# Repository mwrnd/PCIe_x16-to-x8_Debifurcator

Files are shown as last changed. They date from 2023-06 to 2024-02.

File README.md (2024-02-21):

# PCIe x16-to-x8 Debifurcator

Designed for use with the [Alveo U25](https://www.xilinx.com/products/boards-and-kits/alveo/u25.html) which has an x16 PCIe interface that is bifurcated to two x8 interfaces, one for the [SFC9250 X2 GbE Controller](https://www.xilinx.com/products/boards-and-kits/x2-series.html) and the other for the [XCZU19EG FPGA](https://www.xilinx.com/products/silicon-devices/soc/zynq-ultrascale-mpsoc.html#eg). This board connects the FPGA's PCIe x8 interface directly to a host system. The X2 GbE Controller is disconnected and ignored.

Only a straddle-mount PCIe x16 Connector is required, such as: [10025026-10103TLF](https://www.trustedparts.com/en/search/10025026-10103TLF), [10025026-10003TLF](https://www.trustedparts.com/en/search/10025026-10003TLF), or [10146027-A40010LF](https://www.trustedparts.com/en/search/10146027-A40010LF).

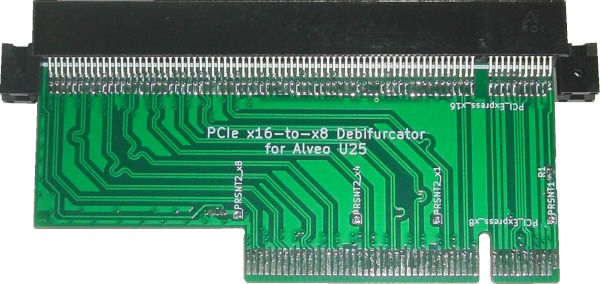
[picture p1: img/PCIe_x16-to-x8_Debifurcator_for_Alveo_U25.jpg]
PCIe x16-to-x8 Debifurcator for Alveo U25


Related Projects: [alveo_u25_notes](https://github.com/mwrnd/alveo_u25_notes), [AlveoU25_JTAG_Adapter](https://github.com/mwrnd/AlveoU25_JTAG_Adapter), [ATX_Boot_Delay](https://github.com/mwrnd/ATX_Boot_Delay)

# Testing and Use Example

I have been able to [successfully test an XDMA design](https://github.com/mwrnd/alveo_u25_notes) using the debifurcator and an Alveo U25 in a system that does not support PCIe Bifurcation.

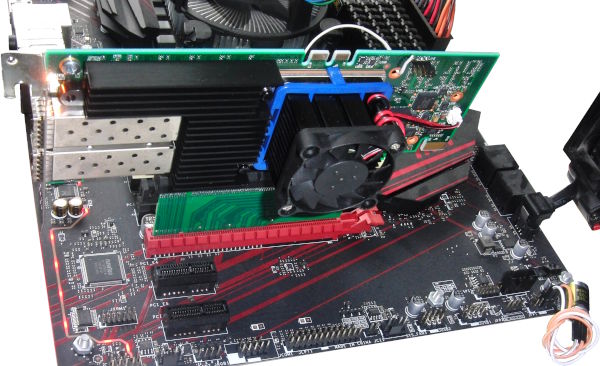
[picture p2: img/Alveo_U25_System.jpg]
PCIe x16-to-x8 Debifurcator with Alveo U25 In-System


The XCZU19EG uses its ARM processor to configure the FPGA's Programmable Logic (PL) bitstream. It is difficult to get this to finish within the [PCIe Specification's 100ms time limit](https://pcisig.com/specifications/ecr_ecn_process?speclib=100+ms). Motherboard boot must be delayed to allow the FPGA to configure itself before PCIe devices are enumerated by the host system. This can be accomplished by toggling the POWER button, then pressing and holding the RESET button for a second before releasing it. Or, [connect a capacitor across the reset pins of an ATX motherboard's Front Panel Header](https://github.com/mwrnd/ATX_Boot_Delay):

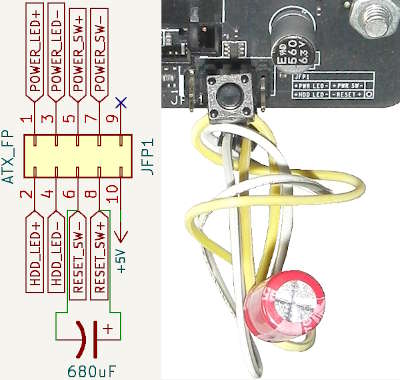
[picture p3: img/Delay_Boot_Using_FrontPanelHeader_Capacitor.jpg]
Motherboard Boot Delay Capacitor


# PCB Layout

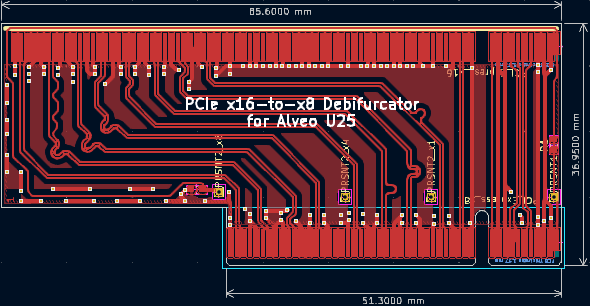
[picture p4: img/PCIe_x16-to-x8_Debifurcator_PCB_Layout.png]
PCIe x16-to-x8 Debifurcator PCB Layout


All differential pairs are length-matched to within 1mm both inter-pair and intra-pair.

# Schematic

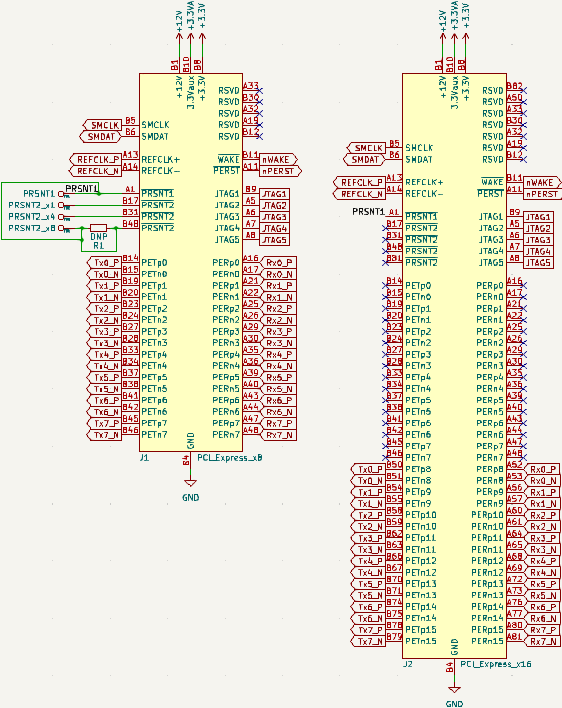
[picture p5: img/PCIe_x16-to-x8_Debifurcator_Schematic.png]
PCIe x16-to-x8 Debifurcator Schematic


# Assembly

The PCIe Connector's Mounting Post needs to be snapped off with needle-nose pliers.

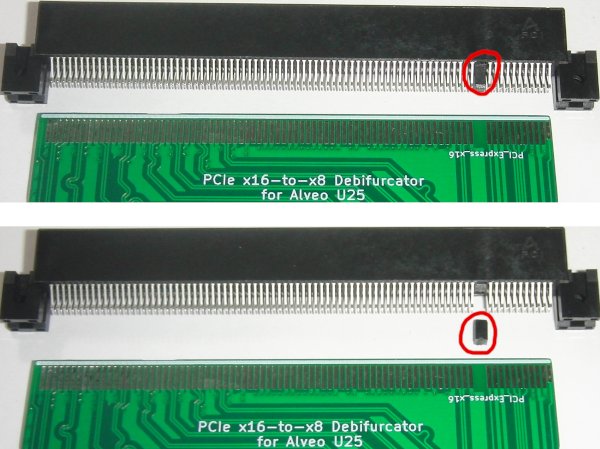
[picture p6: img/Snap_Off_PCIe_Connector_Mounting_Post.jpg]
Snap Off PCIe Connector Mounting Post


# PCB Layer Stackup

4-Layer PCB stackup taken from [JLCPCB](https://jlcpcb.com/capabilities/pcb-capabilities).

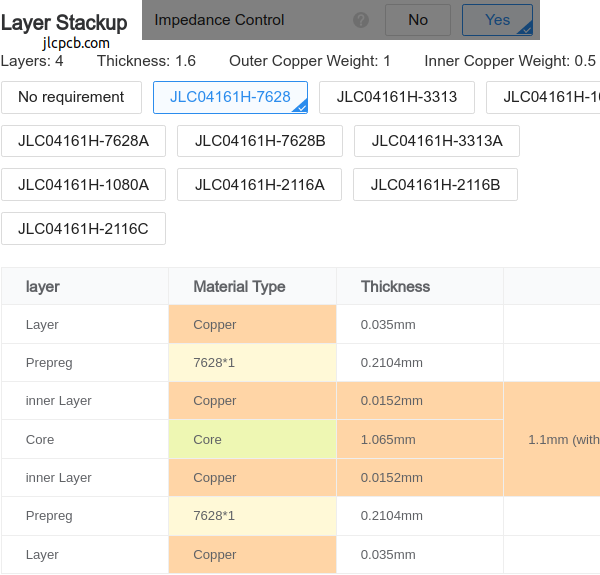
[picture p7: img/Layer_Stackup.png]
PCB Layer Stackup


Differential Impedance parameters were calculated using the [DigiKey Online Calculator](https://www.digikey.com/en/resources/conversion-calculators/conversion-calculator-pcb-trace-impedance).

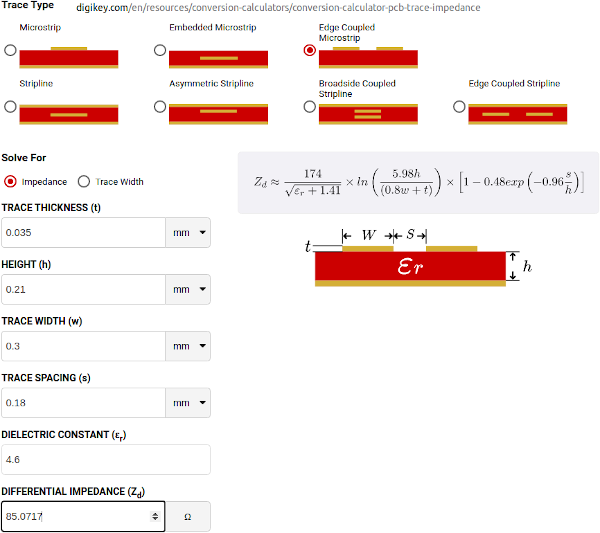
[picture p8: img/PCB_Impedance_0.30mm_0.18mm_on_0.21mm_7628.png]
PCB Differential Impedance Calculation


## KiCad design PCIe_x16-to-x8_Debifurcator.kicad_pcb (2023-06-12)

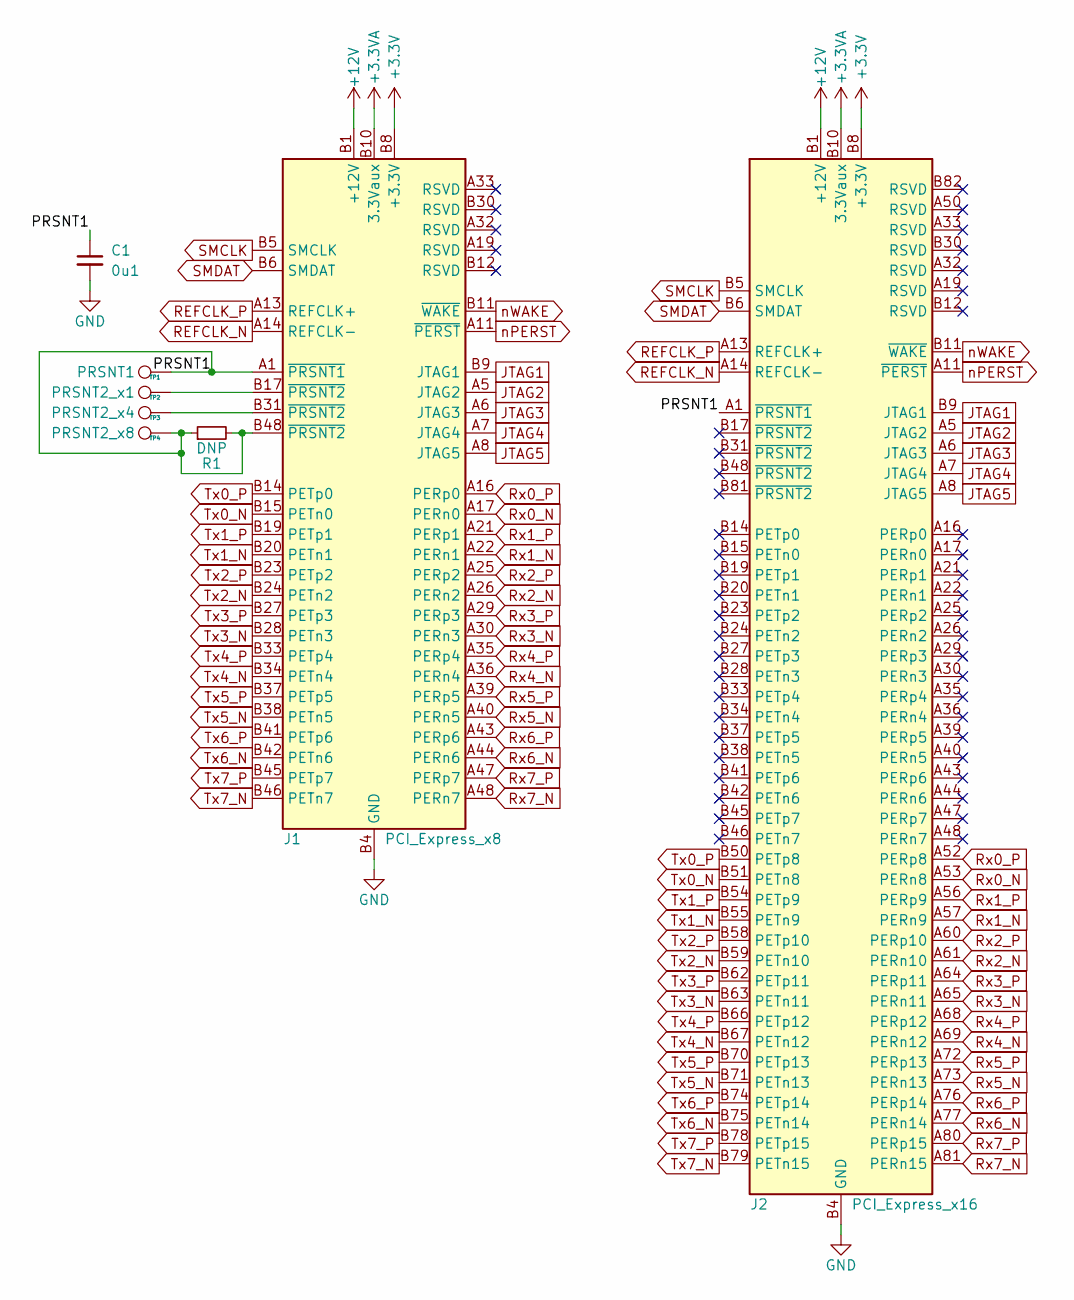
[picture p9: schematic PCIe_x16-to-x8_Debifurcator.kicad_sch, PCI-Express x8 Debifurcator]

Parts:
C1: 0u1; C_0603_1608Metric_Pad1.08x0.95mm_HandSolder
J1: PCI_Express_x8; BUS_PCIexpress_x8
J2: PCI_Express_x16; BUS_PCIexpress_x16
R1: DNP; R_0603_1608Metric
TP1: PRSNT1; PinHeader_1x01_P1.00mm_Vertical
TP2: PRSNT2_x1; PinHeader_1x01_P1.00mm_Vertical
TP3: PRSNT2_x4; PinHeader_1x01_P1.00mm_Vertical
TP4: PRSNT2_x8; PinHeader_1x01_P1.00mm_Vertical

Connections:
+3.3V: J1.A9 (+3.3V), J1.A10 (+3.3V), J1.B8 (+3.3V), J2.A9 (+3.3V), J2.A10 (+3.3V), J2.B8 (+3.3V)
+3.3VA: J1.B10 (3.3Vaux), J2.B10 (3.3Vaux)
+12V: J1.A2 (+12V), J1.A3 (+12V), J1.B1 (+12V), J1.B2 (+12V), J1.B3 (+12V), J2.A2 (+12V), J2.A3 (+12V), J2.B1 (+12V), J2.B2 (+12V), J2.B3 (+12V)
/PRSNT1: C1.1, J1.A1 (~PRSNT1), J1.B48 (~PRSNT2), J2.A1 (~PRSNT1), R1.1, R1.2, TP1.1, TP4.1
GND: C1.2, J1.A4 (GND), J1.A12 (GND), J1.A15 (GND), J1.A18 (GND), J1.A20 (GND), J1.A23 (GND), J1.A24 (GND), J1.A27 (GND), J1.A28 (GND), J1.A31 (GND), J1.A34 (GND), J1.A37 (GND), J1.A38 (GND), J1.A41 (GND), J1.A42 (GND), J1.A45 (GND), J1.A46 (GND), J1.A49 (GND), J1.B4 (GND), J1.B7 (GND), J1.B13 (GND), J1.B16 (GND), J1.B18 (GND), J1.B21 (GND), J1.B22 (GND), J1.B25 (GND), J1.B26 (GND), J1.B29 (GND), J1.B32 (GND), J1.B35 (GND), J1.B36 (GND), J1.B39 (GND), J1.B40 (GND), J1.B43 (GND), J1.B44 (GND), J1.B47 (GND), J1.B49 (GND), J2.A4 (GND), J2.A12 (GND), J2.A15 (GND), J2.A18 (GND), J2.A20 (GND), J2.A23 (GND), J2.A24 (GND), J2.A27 (GND), J2.A28 (GND), J2.A31 (GND), J2.A34 (GND), J2.A37 (GND), J2.A38 (GND), J2.A41 (GND), J2.A42 (GND), J2.A45 (GND), J2.A46 (GND), J2.A49 (GND), J2.A51 (GND), J2.A54 (GND), J2.A55 (GND), J2.A58 (GND), J2.A59 (GND), J2.A62 (GND), J2.A63 (GND), J2.A66 (GND), J2.A67 (GND), J2.A70 (GND), J2.A71 (GND), J2.A74 (GND), J2.A75 (GND), J2.A78 (GND), J2.A79 (GND), J2.A82 (GND), J2.B4 (GND), J2.B7 (GND), J2.B13 (GND), J2.B16 (GND), J2.B18 (GND), J2.B21 (GND), J2.B22 (GND), J2.B25 (GND), J2.B26 (GND), J2.B29 (GND), J2.B32 (GND), J2.B35 (GND), J2.B36 (GND), J2.B39 (GND), J2.B40 (GND), J2.B43 (GND), J2.B44 (GND), J2.B47 (GND), J2.B49 (GND), J2.B52 (GND), J2.B53 (GND), J2.B56 (GND), J2.B57 (GND), J2.B60 (GND), J2.B61 (GND), J2.B64 (GND), J2.B65 (GND), J2.B68 (GND), J2.B69 (GND), J2.B72 (GND), J2.B73 (GND), J2.B76 (GND), J2.B77 (GND), J2.B80 (GND)
JTAG1: J1.B9 (JTAG1), J2.B9 (JTAG1)
JTAG2: J1.A5 (JTAG2), J2.A5 (JTAG2)
JTAG3: J1.A6 (JTAG3), J2.A6 (JTAG3)
JTAG4: J1.A7 (JTAG4), J2.A7 (JTAG4)
JTAG5: J1.A8 (JTAG5), J2.A8 (JTAG5)
unnamed: J1.B17 (~PRSNT2), TP2.1
unnamed: J1.B31 (~PRSNT2), TP3.1
REFCLK_N: J1.A14 (REFCLK-), J2.A14 (REFCLK-)
REFCLK_P: J1.A13 (REFCLK+), J2.A13 (REFCLK+)
Rx0_N: J1.A17 (PERn0), J2.A53 (PERn8)
Rx0_P: J1.A16 (PERp0), J2.A52 (PERp8)
Rx1_N: J1.A22 (PERn1), J2.A57 (PERn9)
Rx1_P: J1.A21 (PERp1), J2.A56 (PERp9)
Rx2_N: J1.A26 (PERn2), J2.A61 (PERn10)
Rx2_P: J1.A25 (PERp2), J2.A60 (PERp10)
Rx3_N: J1.A30 (PERn3), J2.A65 (PERn11)
Rx3_P: J1.A29 (PERp3), J2.A64 (PERp11)
Rx4_N: J1.A36 (PERn4), J2.A69 (PERn12)
Rx4_P: J1.A35 (PERp4), J2.A68 (PERp12)
Rx5_N: J1.A40 (PERn5), J2.A73 (PERn13)
Rx5_P: J1.A39 (PERp5), J2.A72 (PERp13)
Rx6_N: J1.A44 (PERn6), J2.A77 (PERn14)
Rx6_P: J1.A43 (PERp6), J2.A76 (PERp14)
Rx7_N: J1.A48 (PERn7), J2.A81 (PERn15)
Rx7_P: J1.A47 (PERp7), J2.A80 (PERp15)
SMCLK: J1.B5 (SMCLK), J2.B5 (SMCLK)
SMDAT: J1.B6 (SMDAT), J2.B6 (SMDAT)
Tx0_N: J1.B15 (PETn0), J2.B51 (PETn8)
Tx0_P: J1.B14 (PETp0), J2.B50 (PETp8)
Tx1_N: J1.B20 (PETn1), J2.B55 (PETn9)
Tx1_P: J1.B19 (PETp1), J2.B54 (PETp9)
Tx2_N: J1.B24 (PETn2), J2.B59 (PETn10)
Tx2_P: J1.B23 (PETp2), J2.B58 (PETp10)
Tx3_N: J1.B28 (PETn3), J2.B63 (PETn11)
Tx3_P: J1.B27 (PETp3), J2.B62 (PETp11)
Tx4_N: J1.B34 (PETn4), J2.B67 (PETn12)
Tx4_P: J1.B33 (PETp4), J2.B66 (PETp12)
Tx5_N: J1.B38 (PETn5), J2.B71 (PETn13)
Tx5_P: J1.B37 (PETp5), J2.B70 (PETp13)
Tx6_N: J1.B42 (PETn6), J2.B75 (PETn14)
Tx6_P: J1.B41 (PETp6), J2.B74 (PETp14)
Tx7_N: J1.B46 (PETn7), J2.B79 (PETn15)
Tx7_P: J1.B45 (PETp7), J2.B78 (PETp15)
nPERST: J1.A11 (~PERST), J2.A11 (~PERST)
nWAKE: J1.B11 (~WAKE), J2.B11 (~WAKE)

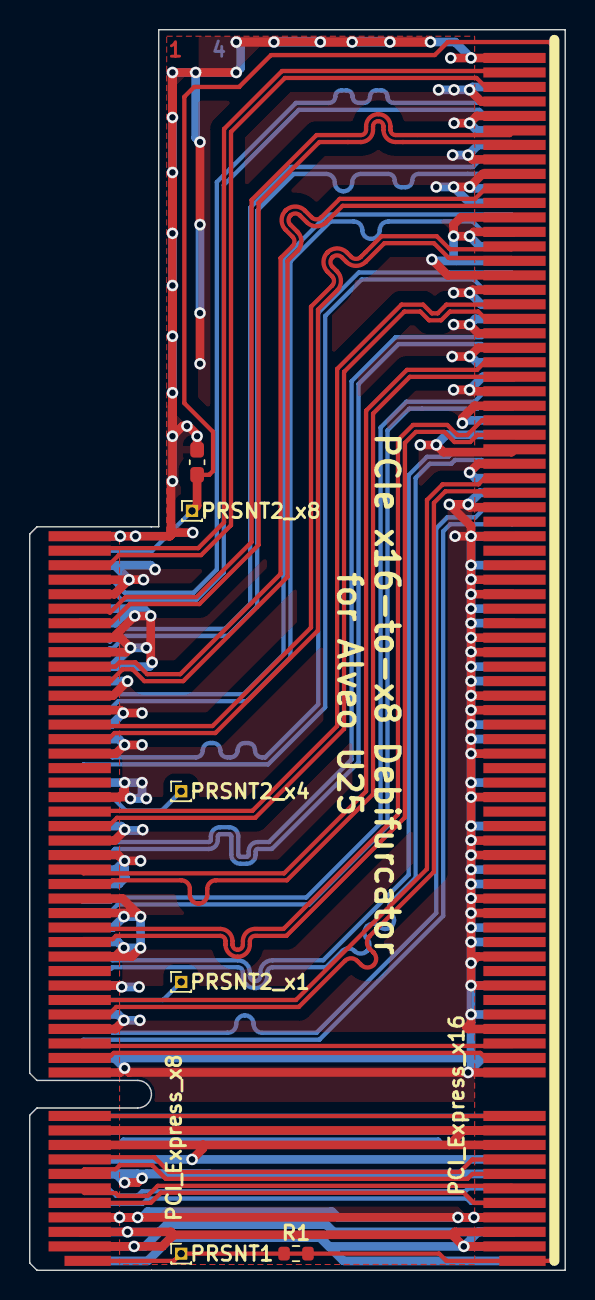
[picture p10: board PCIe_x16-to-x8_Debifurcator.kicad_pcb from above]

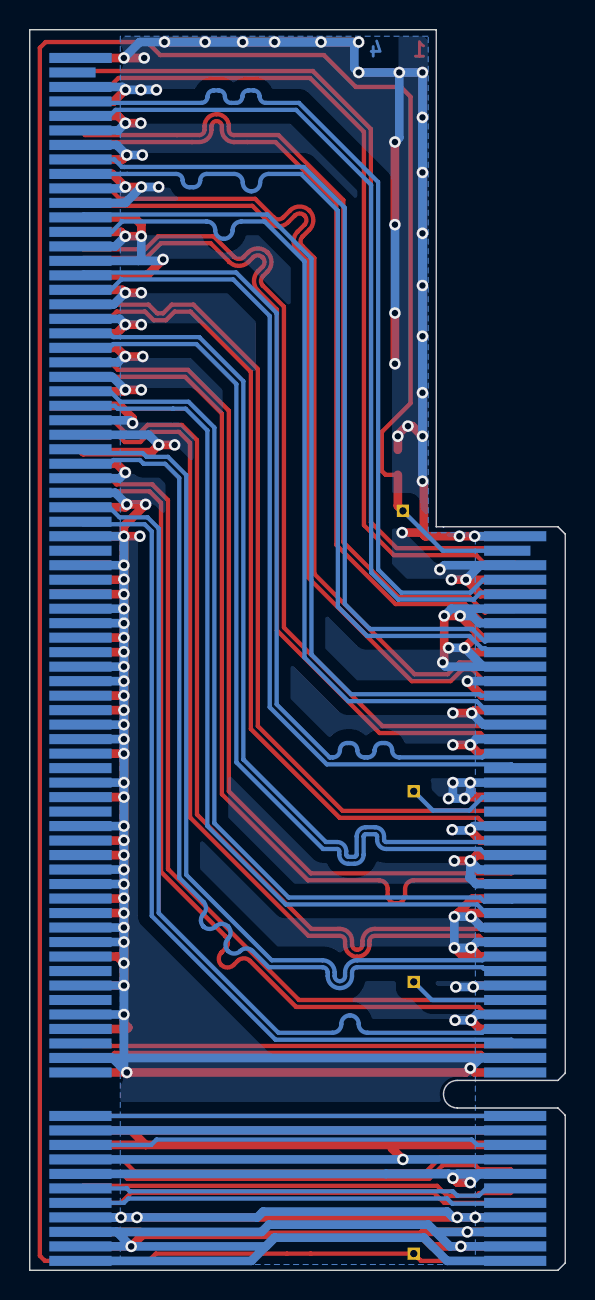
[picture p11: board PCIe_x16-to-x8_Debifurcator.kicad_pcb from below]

Board: 4 copper layers, 37.0 x 85.6 mm, 8 parts (2 on the bottom side), 50 nets.

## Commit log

2023-06-10 First Revision
    [PCIe_x16-to-x8_Debifurcator.kicad_pcb, PCIe_x16-to-x8_Debifurcator.kicad_sch]
2023-06-12 v0.1.1 PCB Layout Updated
    [PCIe_x16-to-x8_Debifurcator.kicad_pcb, PCIe_x16-to-x8_Debifurcator.kicad_sch]
